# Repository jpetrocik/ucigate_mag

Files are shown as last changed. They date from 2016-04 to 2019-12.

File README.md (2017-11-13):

# ucigate_mag

Hardware design and firmware to operate a UCI Starting gate.  Eagle files are avaiable in the hardware directory.  Required 3rd party libraries for compiling the firmware included in libraries directory.  These need to be copied Arudino's library directly. 

eepromburner util copies starting cadence to eprom chip on board.

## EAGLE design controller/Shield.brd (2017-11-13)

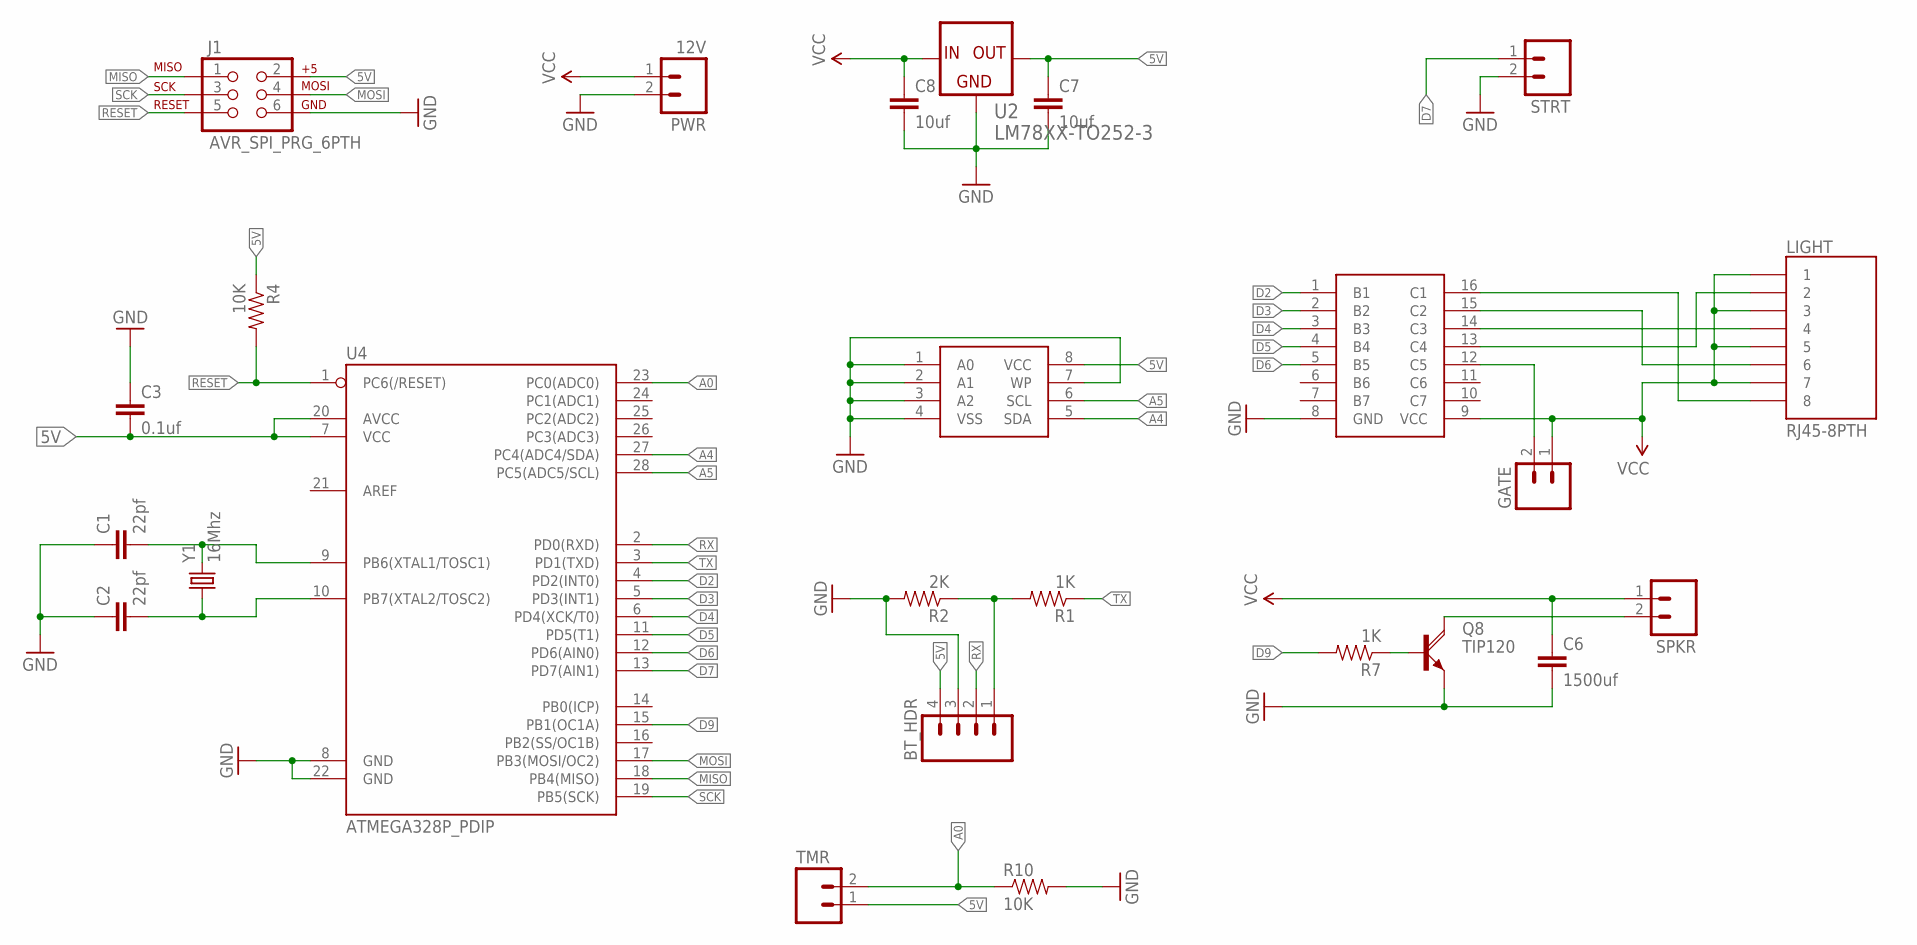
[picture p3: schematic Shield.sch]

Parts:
BT_HDR: M04PTH; 1X04
C1, C2: 22pf; 1206
C3: 0.1uf; 1206
C6: 1500uf; CAP-PTH-5MM
C7, C8: 10uf; CAP-PTH-SMALL
GATE: M023.5MM; SCREWTERMINAL-3.5MM-2
J1: AVR_SPI_PRG_6PTH; 2X3
LIGHT: RJ45-8PTH; RJ45-8
PWR: 12V; SCREWTERMINAL-3.5MM-2
Q8: TIP120; TO220V
R1, R7: 1K; 1206
R2: 2K; 1206
R4, R10: 10K; 1206
SPKR: M023.5MM; SCREWTERMINAL-3.5MM-2
STRT: M023.5MM; SCREWTERMINAL-3.5MM-2
TMR: M023.5MM; SCREWTERMINAL-3.5MM-2
U2: LM78XX-TO252-3; TO252-3
U4: ATMEGA328P_PDIP; DIL28-3
U$1: MC1413D; SO016
U$2: 24AAXXX; SOIC-8-EIAJ
Y1: 16Mhz; HC49US

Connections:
5V: BT_HDR.4, C3.2, C7.1, J1.2, R4.1, TMR.1, U2.3 (OUT), U4.7 (VCC), U4.20 (AVCC), U$2.8 (VCC)
A0: R10.1, TMR.2, U4.23 (PC0(ADC0))
A4: U4.27 (PC4(ADC4/SDA)), U$2.5 (SDA)
A5: U4.28 (PC5(ADC5/SCL)), U$2.6 (SCL)
D2: U4.4 (PD2(INT0)), U$1.1 (B1)
D3: U4.5 (PD3(INT1)), U$1.2 (B2)
D4: U4.6 (PD4(XCK/T0)), U$1.3 (B3)
D5: U4.11 (PD5(T1)), U$1.4 (B4)
D6: U4.12 (PD6(AIN0)), U$1.5 (B5)
D7: STRT.1, U4.13 (PD7(AIN1))
D9: R7.2, U4.15 (PB1(OC1A))
GATE: GATE.2, U$1.12 (C5)
GND: BT_HDR.3, C1.1, C2.1, C3.1, C6.2, C7.2, C8.2, J1.6, PWR.2, Q8.3 (E), R2.2, R10.2, STRT.2, U2.2 (COM), U4.8 (GND), U4.22 (GND), U$1.8 (GND), U$2.1 (A0), U$2.2 (A1), U$2.3 (A2), U$2.4 (VSS), U$2.7 (WP)
MISO: J1.1, U4.18 (PB4(MISO))
MOSI: J1.4, U4.17 (PB3(MOSI/OC2))
unnamed: BT_HDR.1, R1.2, R2.1
unnamed: LIGHT.8, U$1.16 (C1)
unnamed: LIGHT.6, U$1.15 (C2)
unnamed: LIGHT.4, U$1.14 (C3)
unnamed: LIGHT.2, U$1.13 (C4)
unnamed: Q8.2 (C), SPKR.2
unnamed: C1.2, U4.9 (PB6(XTAL1/TOSC1)), Y1.2
unnamed: Q8.1 (B), R7.1
unnamed: C2.2, U4.10 (PB7(XTAL2/TOSC2)), Y1.1
RESET: J1.5, R4.2, U4.1 (PC6(/RESET))
RX: BT_HDR.2, U4.2 (PD0(RXD))
SCK: J1.3, U4.19 (PB5(SCK))
TX: R1.1, U4.3 (PD1(TXD))
VCC: C6.1, C8.1, GATE.1, LIGHT.1, LIGHT.3, LIGHT.5, LIGHT.7, PWR.1, SPKR.1, U2.1 (IN), U$1.9 (VCC)

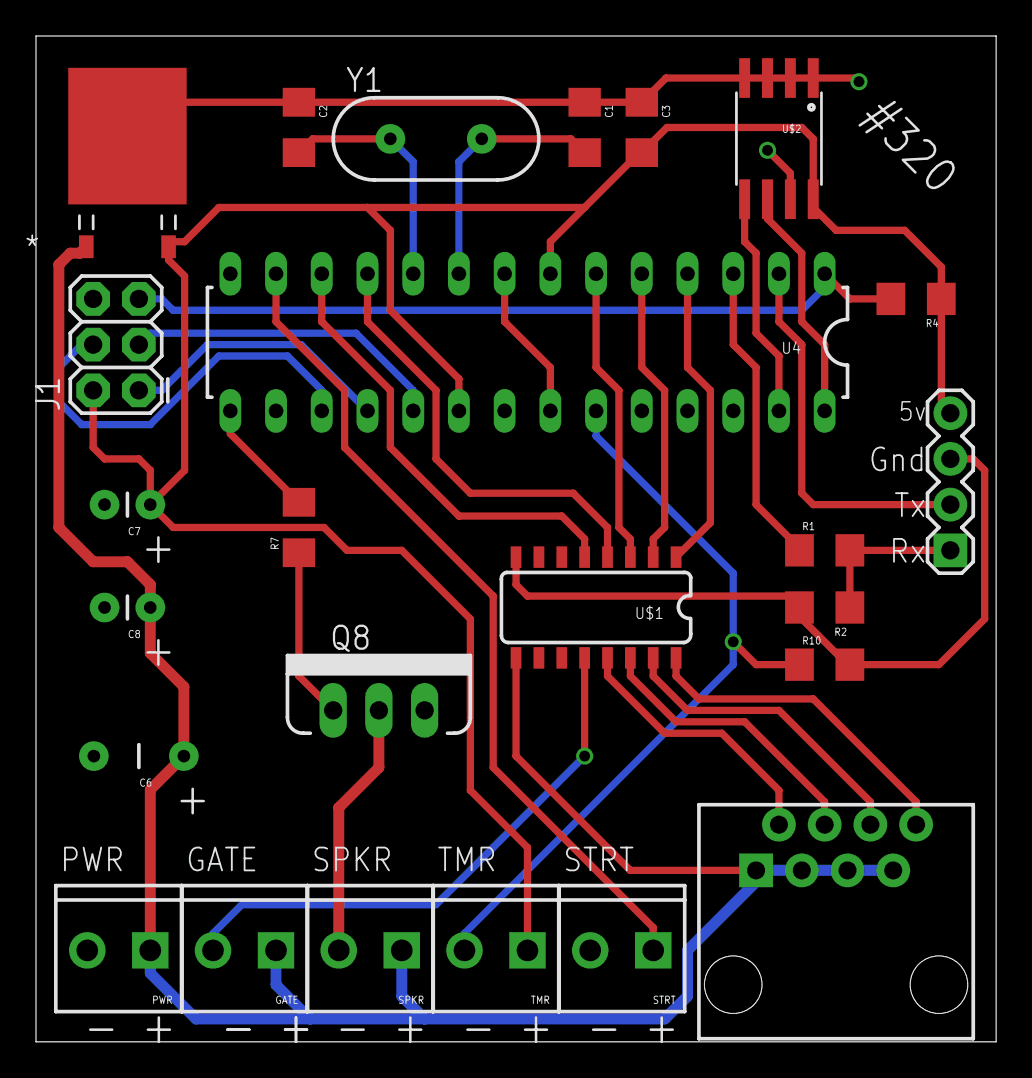
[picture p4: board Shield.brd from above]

Board: 2 copper layers, 53.3 x 55.9 mm, 25 parts (0 on the bottom side), 29 nets.

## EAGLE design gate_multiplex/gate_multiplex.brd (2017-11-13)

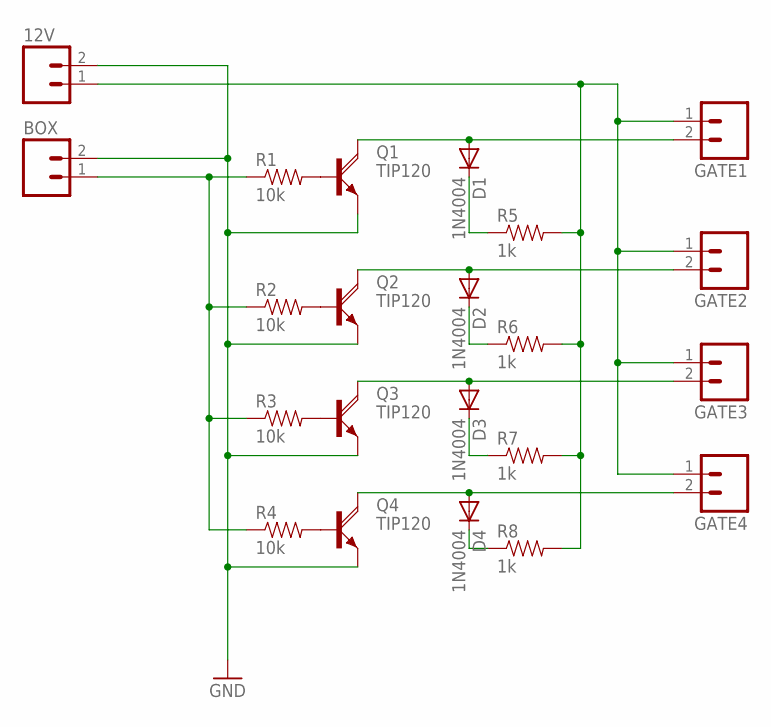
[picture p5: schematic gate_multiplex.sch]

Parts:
12V: M02PTH; 1X02
BOX: M02PTH; 1X02
D1, D2, D3, D4: 1N4004; DO41-10
GATE1, GATE2, GATE3, GATE4: M02PTH; 1X02
Q1, Q2, Q3, Q4: TIP120; TO220V
R1, R2, R3, R4: 10k; 1206
R5, R6, R7, R8: 1k; 1206

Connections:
GND: 12V.2, BOX.2, Q1.3 (E), Q2.3 (E), Q3.3 (E), Q4.3 (E)
unnamed: D1.A, GATE1.2, Q1.2 (C)
unnamed: D2.A, GATE2.2, Q2.2 (C)
unnamed: D3.A, GATE3.2, Q3.2 (C)
unnamed: D4.A, GATE4.2, Q4.2 (C)
unnamed: BOX.1, R1.1, R2.1, R3.1, R4.1
unnamed: Q2.1 (B), R2.2
unnamed: Q1.1 (B), R1.2
unnamed: Q3.1 (B), R3.2
unnamed: Q4.1 (B), R4.2
unnamed: 12V.1, GATE1.1, GATE2.1, GATE3.1, GATE4.1, R5.2, R6.2, R7.2, R8.2
unnamed: D1.C, R5.1
unnamed: D2.C, R6.1
unnamed: D3.C, R7.1
unnamed: D4.C, R8.1

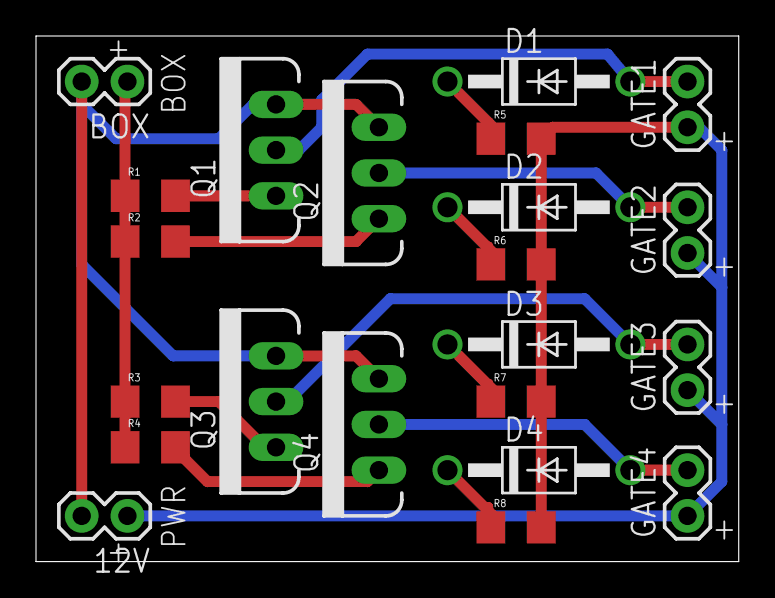
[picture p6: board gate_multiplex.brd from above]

Board: 2 copper layers, 39.0 x 29.2 mm, 22 parts (0 on the bottom side), 15 nets.

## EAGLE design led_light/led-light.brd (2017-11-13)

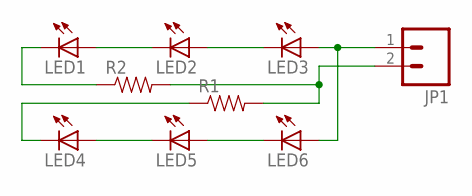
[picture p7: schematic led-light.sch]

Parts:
JP1: M02PTH; 1X02
LED1, LED2, LED3, LED4, LED5, LED6: LED5MM
R1, R2: RESISTORPTH-1/4W; AXIAL-0.4

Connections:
unnamed: LED1.K (C), R2.P$1 (1)
unnamed: LED2.A, LED3.K (C)
unnamed: LED1.A, LED2.K (C)
unnamed: LED4.K (C), R1.P$1 (1)
unnamed: LED4.A, LED5.K (C)
unnamed: LED5.A, LED6.K (C)
unnamed: JP1.1, LED3.A, LED6.A
unnamed: JP1.2, R1.P$2 (2), R2.P$2 (2)

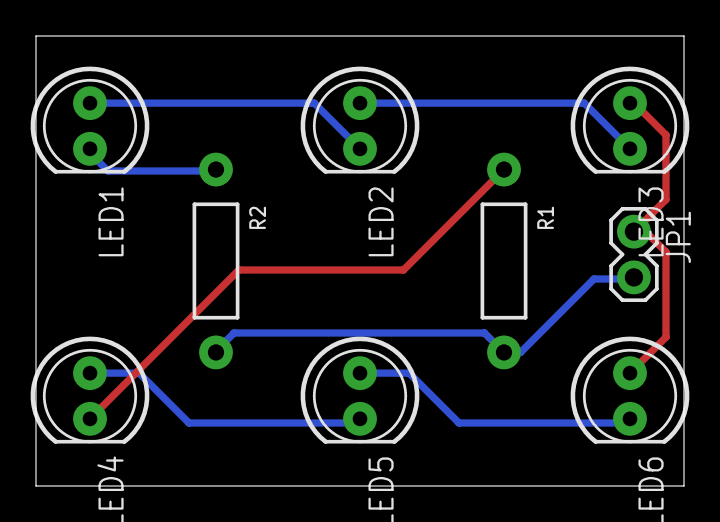
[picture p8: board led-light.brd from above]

Board: 2 copper layers, 36.0 x 25.0 mm, 9 parts (0 on the bottom side), 8 nets.

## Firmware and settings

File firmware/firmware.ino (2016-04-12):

#include <stdint.h>
#include <avr/interrupt.h>
#include <avr/io.h>

#include <ByteBuffer.h>
#include <EE24CCxxx.h>
#include <TMRpcm.h>
#include <Wire.h>

#include "configuration.h"

#define TRUE 1
#define FALSE 0

/**
 * Firmware Version number
 */
#define FIRMWARE_VERSION "1.1.1"

/**
 * Serial input buffer
 */
byte serialInput[100];
int serialSize = 0;

long startTime = 0;
int cadenceStarted = FALSE;
int timerStarted = FALSE;

/**
 * Recalibrated each start, used as a threadhold to indicate timer was triped
 */
int MAT_SENSOR_THRESHOLD = 0;

/**
 * Audio PWM player
 */
TMRpcm trmpcm;

void setup() {
  // initialize serial communication for debug
  SerialPort.begin(9600);

  //Turn on i2c and set to 400Hz
  Wire.begin();
  TWBR = 12;

  //setup pwvm audio
  trmpcm.speakerPin=SPEAKER;
  trmpcm.setVolume(6);

  //set pin modes
  pinMode(GATE, OUTPUT);
  pinMode(LIGHT_RED, OUTPUT);
  pinMode(LIGHT_YELLOW_1, OUTPUT);
  pinMode(LIGHT_YELLOW_2, OUTPUT);
  pinMode(LIGHT_GREEN, OUTPUT);
  pinMode(START, INPUT_PULLUP);

  //disable hum of speaker before first cadence
  pinMode(SPEAKER, OUTPUT);
  digitalWrite(SPEAKER, LOW);

  //turn on magnet
  digitalWrite(GATE, HIGH);

  //performance light show to indicate box is on
  digitalWrite(LIGHT_RED, HIGH);
  delay(250);
  digitalWrite(LIGHT_YELLOW_1, HIGH);
  delay(250);
  digitalWrite(LIGHT_YELLOW_2, HIGH);
  delay(250);
  digitalWrite(LIGHT_GREEN, HIGH);
  delay(250);
  for (int i=0;i<5;i++){
    digitalWrite(LIGHT_RED, HIGH);  
    digitalWrite(LIGHT_YELLOW_1, HIGH);
    digitalWrite(LIGHT_YELLOW_2, HIGH);
    digitalWrite(LIGHT_GREEN, HIGH);
    delay(100);
    digitalWrite(LIGHT_RED, LOW);
    digitalWrite(LIGHT_YELLOW_1, LOW);
    digitalWrite(LIGHT_YELLOW_2, LOW);
    digitalWrite(LIGHT_GREEN, LOW);
    delay(100);
  }

}

/**
 * Sends event via serial, aka blueooth
 *
 * Message Format: BMX99CMD99ARGS
 * BMX = start of message indicator
 * 99 = number of byte of command <- a single byte
 * CMD = the command sent
 * 99 = number of bytes of args <- a single byte 0x00 - 0xFF
 * ARGS = the args for this command
 * 
 */
void sendEvent(String cmd, String args){
  int cmdSize = cmd.length();
  int argSize = args.length();

  SerialPort.print("BMX");
  SerialPort.print((char)cmdSize);
  SerialPort.print(cmd);
  SerialPort.print((char)argSize);
  SerialPort.print(args);
}

/**
 * Returns the software version number
 */
void version() {
  sendEvent("SW_VERSION",FIRMWARE_VERSION);
}

/**
 * Main loop
 */
void loop() {

  //process any serial commands
  processSerialInput();

  long currentTime = millis();

  /**
   * Cadence started from push button, only when cadence not
   * running. 
   */
  if (!digitalRead(START) && !cadenceStarted) {
    cadenceStarted=TRUE;
    sendEvent("EVNT_CADENCE_STARTED","");

    for (int i=0; i<5; i++){
      tone(SPEAKER, 1150, 250);
      delay(500);
    }

    delay(8000);
    startTime = startCadence();
  }

  /*
   * Check Sensor Matt
   */
  if (timerStarted) {
    int timerMat = analogRead(TIMER);
    if ( timerMat > MAT_SENSOR_THRESHOLD ){
      sendEvent("EVNT_TIMER_1", String(currentTime-startTime));
      timerStarted=FALSE;
    }
  }

  /* 
   * 3 seconds after gate drops reset all lights and enable magnet
   * so gate can be lifted for next start
   */
  if ((startTime+3000) < currentTime && cadenceStarted){
    resetGate();
    cadenceStarted = FALSE;
  }

}

/**
 * Start the cadence, blocking until cadence completes
 */
long startCadence(){
  int randNumber;

  calibrateTimer();

  // "OK RIDERS RANDOM START" : 1:50+1:80 sec
  sendEvent("EVNT_OK_RIDERS","");
  trmpcm.play(0,13224);
  digitalWrite(LIGHT_RED, HIGH);
  digitalWrite(LIGHT_YELLOW_1, HIGH);
  digitalWrite(LIGHT_YELLOW_2, HIGH);
  digitalWrite(LIGHT_GREEN, HIGH);
  delay(3300);

  // "RIDERS READY - WATCH THE GATE" : 2.00 sec
  sendEvent("EVNT_RIDERS_READY","");
  trmpcm.play(32000,17535);
  digitalWrite(LIGHT_GREEN, LOW);
  delay(670);
  digitalWrite(LIGHT_YELLOW_2, LOW);
  delay(670);
  digitalWrite(LIGHT_YELLOW_1, LOW);
  delay(670);
  digitalWrite(LIGHT_RED, LOW);
  delay(100);
  trmpcm.disable();

  //Random delay .1 - 2.7 sec
  //offical delay of .1 was to fast, using .250
  randNumber = random(.550, 2700);
  delay(randNumber);        

  //Red Light
  sendEvent("EVNT_RED_LIGHT","");
  lightOn(LIGHT_RED,60);

  //Yellow Light
  sendEvent("EVNT_YELLOW_1_LIGHT","");
  lightOn(LIGHT_YELLOW_1,60);

  //drop gate 120ms early to compensate for magnet field calpse
  digitalWrite(GATE, LOW);

  //Yellow Light
  sendEvent("EVNT_YELLOW_2_LIGHT","");
  lightOn(LIGHT_YELLOW_2,60);

  //Turns green light an return 
  //immediately as buzzer plays
  sendEvent("EVNT_GREEN_LIGHT","");
  digitalWrite(LIGHT_GREEN, HIGH);
  tone(SPEAKER, 632, 2250);

  timerStarted = TRUE;

  return millis();
}

void resetGate(){
  digitalWrite(GATE, HIGH);
  digitalWrite(LIGHT_RED, LOW);
  digitalWrite(LIGHT_YELLOW_1, LOW);
  digitalWrite(LIGHT_YELLOW_2, LOW);
  digitalWrite(LIGHT_GREEN, LOW);
}

void lightOn(int light, int msec){
  digitalWrite(light, HIGH);
  tone(SPEAKER, 632, msec);
  delay(msec+60);
  noTone(SPEAKER);
}


void shiftArray(byte data[], int offset, int length){

  for (int i=offset;i<length;i++){
    data[i-offset]=data[i];
  }

}

String toStr(byte data[], int offset, int length){
  int endOffset = offset+length;
  String value = "";
  value.reserve(length);

  for (int i = offset ; i<endOffset ; i++){
    value += (char)data[i];
  }

  return value;
}

void performCommand(String cmd, String args){
  if (cmd.equals("GET")){
    if (args.equals("SW_VERSION")) {
      version();
    }
  } 
  else if (cmd.equals("START_CADENCE")) {
    if (cadenceStarted==FALSE){
      sendEvent("EVNT_CADENCE_STARTED","");
      cadenceStarted=TRUE;
      delay(500);
      startTime = startCadence();
    }
  } 
}


/**
 * Resets the serial buffer, clears out the input stream and 
 * resets previously read data
 **/
void resetSerial(){
  while (SerialPort.available()) {
    SerialPort.read(); 
  }
  serialSize=0;
}  

void processSerialInput() {

  //read everyting we have recieved adn buffer
  while (SerialPort.available()) {
    serialInput[serialSize++] = SerialPort.read(); 
    if (serialSize>100){
      sendEvent("ERROR","BUFFER_LIMIT");
      resetSerial();
      return;
    }   
  }

  //not a valid cmd, yet
  if(serialSize<5)
    return;

  //look for cmd seq
  for (int i=0; i < serialSize; i++){

    //found cmd seq
    if (serialInput[i] == 'B' && serialInput[i+1] == 'M' && serialInput[i+2] == 'X'){
      i+=3;

      //read cmd
      if (i >= serialSize) return;
      int cmdSize = 0 | serialInput[i++];

      if (i+cmdSize > serialSize) return;
      String cmd = toStr(serialInput, i, cmdSize);
      i+=cmdSize;

      //read args
      if (i >= serialSize) return;
      int argSize = 0 | serialInput[i++];

      if (i+argSize > serialSize) return;
      String args = toStr(serialInput, i, argSize);
      i+=argSize;

      performCommand(cmd, args);

      //reposition unread to start of buffer
      shiftArray(serialInput, i, serialSize);
      serialSize=serialSize-i;

      return;
    } 
  }

  //no valid command found, wiping out data
  serialSize=0;
}

void calibrateTimer(){
  //Get base reading for timing matt
  int reading = 0;
  for (int i=0; i<5; i++){
    reading += analogRead(TIMER);
    delay(20);
  }
  MAT_SENSOR_THRESHOLD=reading/5+300;

}

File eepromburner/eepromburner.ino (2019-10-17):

#include <stdint.h>
#include <avr/interrupt.h>
#include <avr/io.h>
#include <avr/pgmspace.h>

#include <Wire.h>
#include <ByteBuffer.h>
#include <EE24CCxxx.h>
#include <TMRpcm.h>

#define EEPROM1 0x50

#include "cadencepart2.h"


void loop(){
  digitalWrite(13,HIGH);
  delay(250);
  digitalWrite(13,LOW);
  delay(250);

}

void writeEEPROM(const unsigned int address, const byte* data, int length) 
{

  Wire.beginTransmission(EEPROM1);
  Wire.write( address >> 8); 
  Wire.write( address & 0xFF);

  for (int i=0; i<length;i++){
    Wire.write(pgm_read_byte(data+i));

    /*
     * EEPROM memory page 64 but Arduino buffer is 
     * only 32 plus address bytes, using 16 because
     * evenly devides into 64
     */
    if (i>0 && (i+1)%16==0){
      Wire.endTransmission();
      delay(6);  // needs 5ms for page write

      Wire.beginTransmission(EEPROM1);
      Wire.write( address+i+1 >> 8); 
      Wire.write( address+i+1 & 0xFF);
    }
  }

  Wire.endTransmission();
  delay(6);  // needs 5ms for page write

}

void readEEPROM(unsigned int address, unsigned int length ) 
{
  Wire.beginTransmission(EEPROM1);
  Wire.write( (address >> 8) & 0xFF); 
  Wire.write( (address >> 0) & 0xFF);
  Wire.endTransmission();

  Wire.requestFrom(EEPROM1, length);
  while (Wire.available()) 
  {
    byte data = Wire.read();
  }
}



void setup()
{

  //initalized i2c and set to 400Hz
  Wire.begin();
  TWBR = 12;

  pinMode(13,OUTPUT);
  digitalWrite(13,HIGH);
  writeEEPROM(cadence_start, &cadence[0], sizeof(cadence));
  digitalWrite(13,LOW);
}

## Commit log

2014-12-06 Rename to firmware
    [configuration.h]
2016-04-12 Updared for board v3
    [configuration.h]
2017-11-13 Merged to signal project for hard and firmware
    [Shield.brd, Shield.sch, configuration.h]
2017-11-13 Switched wiring for lights to clean up board layout
    [Shield.brd, Shield.sch]
2017-11-13 Adding led lights and mulitplex board
    [gate_multiplex.brd, gate_multiplex.sch, led-light.brd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]
2019-12-29 Adding android app
    [Shield.brd, Shield.sch]

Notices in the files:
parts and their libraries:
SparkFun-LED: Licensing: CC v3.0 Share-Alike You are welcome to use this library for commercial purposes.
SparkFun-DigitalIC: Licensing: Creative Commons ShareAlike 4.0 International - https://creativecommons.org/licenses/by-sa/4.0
